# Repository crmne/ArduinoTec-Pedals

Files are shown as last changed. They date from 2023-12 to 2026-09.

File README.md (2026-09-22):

# ArduinoTec-Pedals

Turn an ATmega32u4 board, two analog pedal sensors and an HX711 load-cell
amplifier into standalone USB racing pedals. Originally made for Fanatec
ClubSport V1/V2 pedals; other pedals can work with compatible sensors and wiring.
The pedals connect to your **computer by USB**, separately from your wheelbase.

**0.2.0 release candidate 1:** intended for hardware testing, not a stable
release. The firmware builds for all three boards below and passes simulated
regression tests. It has not yet been tested on physical pedals. Read the
[release notes](docs/releases/0.2.0-rc.1.md) and do the checks below before
using it in a race.

This version adds saved calibration, automatic sensor direction detection,
a guided setup tool, a 1,000 Hz report target, brake fault detection, and builds
with pinned dependencies. Hardware limits still apply: the HX711 supplies
**10 or 80 new brake readings per second**, not 1,000.

## What you need

| Part | Requirement |
| --- | --- |
| Controller | Arduino Leonardo, Arduino Micro, or ATmega32u4 Pro Micro **5 V / 16 MHz** |
| Throttle and clutch | Analog sensors: stock compatible Hall sensors or potentiometers |
| Brake | Load cell connected to an HX711 amplifier, channel A |
| Wiring | USB data cable, connectors, insulated wire, mounting/strain relief |
| Tools | Multimeter; soldering iron, solder and heat shrink for permanent assembly |
| Computer | Arduino IDE for installation; Python 3.9+ for the guided setup tool |

Uno/Nano with ATmega328P, Teensy, RP2040, and 3.3 V / 8 MHz Pro Micro boards are
not targets of the supplied binaries. A board with a similar shape is not
necessarily compatible. Two-pedal builds are possible from source by setting
`CLUTCH_ENABLED` to `false`; downloadable defaults expect all three pedals.

The original Hall sensors' voltage rating must be established before powering
them. A 5 V controller does **not** mean an unknown sensor tolerates 5 V.
See [wiring and assembly](docs/wiring.md) for the pin table, load-cell types,
checks before connecting USB, and the original circuit drawing.

## 1. Wire and check the pedals

Follow [the wiring guide](docs/wiring.md). Prototype and verify sensor readings
before making permanent joints. Disconnect the original controller from any
sensors you reconnect here. Do not connect this USB controller to the wheelbase
pedal socket.

Default signals are throttle **A0**, clutch **A2**, HX711 **DT → D3** and
**SCK → D5**, with a common ground. Use the labels printed on your specific
board and module. The old brake sensitivity potentiometer is optional and
ignored by default: calibration now sets the pressure that means full braking.

## 2. Install the firmware

### Arduino IDE: the easiest starting point

1. Download this repository using **Code → Download ZIP**, then extract it.
2. Install [Arduino IDE](https://www.arduino.cc/en/software). In Boards Manager,
   install **Arduino AVR Boards 1.8.8**. For a Pro Micro, also install
   **SparkFun AVR Boards 1.1.13** using the additional board URL below.
3. In Library Manager, install **HX711_ADC 1.2.12** by Olav Kallhovd.
4. Download [ArduinoJoystickLibrary v2.1.1](https://github.com/MHeironimus/ArduinoJoystickLibrary/archive/refs/tags/v2.1.1.zip).
   In the IDE choose **Sketch → Include Library → Add .ZIP Library**.
5. Open `ArduinoTec-Pedals/ArduinoTec-Pedals.ino`. Keep **all files in that
   folder together**; downloading just the `.ino` does not work.
6. Select your board and USB port. For SparkFun Pro Micro, select
   **ATmega32U4 (5V, 16 MHz)** under Processor. Click **Upload**.
7. Close the IDE's Serial Monitor before using the setup tool.

SparkFun's additional Boards Manager URL (IDE Settings/Preferences):

```text
https://raw.githubusercontent.com/sparkfun/Arduino_Boards/master/IDE_Board_Manager/package_sparkfun_index.json
```

No pedal motion is reported until you complete and save calibration.

### Prebuilt firmware: no compilation

When available, download the `pedals-VERSION.zip` asset from
[Releases](https://github.com/crmne/ArduinoTec-Pedals/releases), or a development
artifact from [Actions](https://github.com/crmne/ArduinoTec-Pedals/actions).
Extract it. The package includes three board-specific HEX files, this guide,
and the setup tool. [The prebuilt installation guide](docs/install-prebuilt.md)
shows how to choose and upload the correct file without replacing your bootloader.

## 3. Calibrate once

Open a terminal in the extracted project/package folder. Create a Python
environment and install the small serial dependency:

```sh
python3 -m venv .venv
source .venv/bin/activate
python -m pip install -r tools/requirements.txt
python tools/pedals.py ports
```

On Windows, use `py -3 -m venv .venv`, then `.venv\Scripts\activate.bat` in
Command Prompt (or `.venv\Scripts\Activate.ps1` in PowerShell). The remaining
`python` commands are the same. On macOS, the port is typically
`/dev/cu.usbmodem…`; on Linux it is usually `/dev/ttyACM…`; Windows uses `COM…`.
Choose the port that appears when you plug in the pedals.

Replace the example port with yours:

```sh
python tools/pedals.py calibrate --port /dev/ttyACM0
```

The tool guides you through:

1. Release every pedal and keep your feet clear.
2. Hold throttle fully pressed, then clutch fully pressed.
3. Hold the brake at the pressure you want to represent **100% braking**.
4. Keep still during each capture (about 0.8 seconds).
5. Review the captured endpoints, release everything, and type **SAVE**.

Calibration is stored in the controller's EEPROM and survives power cycles.
It supports sensors whose readings increase or decrease when pressed. Default
deadzones are 0.5% at each end; `--deadzone-percent 1` sets 1% instead.
The brake capture sets a personal force preference; it is not a measurement
of kilograms without separate mechanical/load-cell calibration.

Press Ctrl+C or decline SAVE to cancel. Previous saved settings are retained.
An abandoned session expires after two minutes without a command. Keep games
closed during setup: output resumes after save, cancel or expiry. A subsequent
capture of the released position requires recapturing all full endpoints.

## 4. Check, then drive

```sh
python tools/pedals.py info --port /dev/ttyACM0
python tools/pedals.py monitor --port /dev/ttyACM0 --seconds 10
```

Check that every released pedal reports zero, each pressed pedal reaches 32767
in this tool, and the others remain at zero. Unplug/replug USB and verify the
calibration remains. The USB library maps this range into 16-bit HID fields;
your game or OS may display a different number for the same full travel.

In your game, bind throttle, brake and clutch separately. This firmware uses
the throttle, brake and Rx (clutch) axes. Clear old game calibration and rebind
if upgrading from the original firmware. The new USB device type is joystick;
Windows/Linux enumeration and individual games still need physical validation.

Linux tools such as `evtest` or `evdev-joystick` can inspect the event device.
`jscal` calibrates the separate legacy `/dev/input/js*` interface. They cannot
save settings on this controller; use the supplied tool for that. See
[calibration protocol and Linux notes](docs/calibration.md).

For a small brake-zero drift after warming up, release it and run:

```sh
python tools/pedals.py tare --port /dev/ttyACM0
```

This adjusts only the current session's brake zero while retaining its travel.
For a lasting change, run the full calibration again. The firmware never
silently tares a pressed brake when plugged in.

## Performance: what the numbers mean

| Part of the system | Capability / limit |
| --- | --- |
| Firmware report schedule | Target 1,000 reports/s, one complete report per interval |
| USB endpoint | Requests 1 ms polling; delivery depends on the host |
| Hall sensors | 10-bit ADC: up to 1,024 raw counts across the entire input voltage range |
| Brake ADC | HX711: 24-bit raw output, **10 or 80 samples/s** selected in hardware |
| Calibrated output | 0–32767 (32,768 possible values), mapped into 16-bit USB fields |
| Actual precision / end-to-end latency | Not measured yet; depends on mechanics, signal span, noise, filtering and host |

`monitor` reports observed firmware submission/sampling rates. Repeating the
latest brake reading at 1,000 Hz does not create new brake measurements.
80 Hz gives a new conversion about every 12.5 ms; 10 Hz gives one about every
100 ms. The HX711 and library filters add delay. The default library's filter
still uses three conversions even with `setSamplesInUse(1)`.

See [performance and measurement](docs/performance.md) for 80 Hz setup, the
filter tradeoff, and a validation checklist. We keep your existing hardware;
software cannot remove the HX711's conversion-rate limit.

## Troubleshooting

| Symptom | What to check |
| --- | --- |
| No serial port | Use a USB **data** cable, check the board selection and OS port permissions. Unplug/replug to identify it. |
| Port busy / access denied | Close Serial Monitor and other tools. On Linux inspect the device's group and follow your distribution's serial-access instructions; do not run the whole setup as root. |
| `BRAKE_NOT_READY` | Wait two seconds after power-on. Check HX711 power, ground, DT/D3 and SCK/D5; a stalled or saturated input is rejected. |
| `UNSTABLE_HOLD_STILL` | Repeat the capture holding the pedal still. Inspect loose wiring, sensor mounting and raw noise. The tool cancels the session on an error. |
| `TRAVEL_TOO_SMALL` | Check sensor/magnet movement or load-cell wiring; released and full readings are too close. |
| Pedals remain at zero | Run `info`; calibration may be missing or invalid. Check that the firmware configuration matches the saved calibration. |
| Brake falls to zero during use | No valid conversion arrived for 250 ms, or the input is invalid/saturated. Inspect the raw readings and wiring. |
| Upload fails | Select the exact board/clock. Pro Micro bootloaders may need reset/double-reset to expose a temporary upload port; see the board maker's instructions. |
| Missing header / wrong Joystick library | Keep the entire sketch folder and install the named library/version above; several unrelated libraries have similar names. |

## Development and releases

[Developer instructions](docs/development.md) cover tests, the pinned build
script, package contents and releases. Pushes and pull requests run simulated
firmware tests, setup-tool tests and builds for Leonardo, Micro and Pro Micro.
Version tags must match the firmware version and be reachable from `master`;
CI prepares a **draft release** with binaries, sources and checksums for review.

This project builds on [jssting/ArduinoTec-Pedals](https://github.com/jssting/ArduinoTec-Pedals).
The September 2026 firmware/setup changes are maintained here. The original
history, circuit assets and [GPL-3.0 license](LICENSE) are retained.

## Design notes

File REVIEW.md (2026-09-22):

# Initial review and improvement plan — 2026-09-22

This is the historical review before the calibration implementation. Its
remaining-work list and proposed protocol are superseded by the current
[README](README.md), [protocol](docs/calibration.md), and
[development/validation guide](docs/development.md). Hardware validation remains
outstanding.

User-visible UI impact: no graphical UI changes. The reliability patch changes
pedal reports on zero/negative readings and near deadzones. Physical pedal and
game testing is still required before claiming a hardware issue resolved.

The project is a useful, small hardware prototype. Its main weakness is implicit
calibration and fragile sampling/output behavior, not a need for more classes.
Keep the sketch as orchestration; extract only shared arithmetic and persistent
configuration that can be tested without hardware.

## Reliability patch

- Always report each axis, including a sensor reading of zero. Previously the
  `val > 0` guards left old values on USB; a released brake could stay pressed,
  and a decreasing Hall sensor reaching ADC zero could stop updating.
- Retain the last brake conversion between HX711 samples. Previously a local
  variable reset to zero every loop and output depended on the guards above.
- Poll HX711 from the main loop. Previously `getData()` could read the multi-byte
  sample dataset while the interrupt modified it. The library supports polling.
- Clamp negative brake readings to zero and bound positive float-to-int
  conversion before applying the sensitivity pot and output limits.
- Share deadzone clipping across axes, apply the brake lower deadzone after
  sensitivity adjustment, and prevent a negative ceiling during startup.
- Use the same dual-input averaging for baseline capture and live readings.
- Send one complete USB report per loop instead of a report per setter.

## Remaining work, in priority order

1. **Explicit, persistent calibration.** Startup baselines require released
   pedals, use a maximum of 25 samples, and cannot distinguish noise from rest.
   Continuously learned maxima move when an outlier arrives and only clip;
   they do not map physical full travel to USB full scale. Store released and
   fully pressed endpoints, direction, deadzones, and desired brake force.
   Normalize each calibrated axis to 0–1023 with 32-bit intermediate math;
   reject endpoints with insufficient span. Avoid `abs()` treating movement
   in the wrong direction as valid pressure.
2. **Sensor health and noise.** A disconnected HX711 can retain its last brake
   value indefinitely, and startup failure loops forever. Add a timestamp and
   explicit fault status, decide a timeout from measured 10/80 SPS behavior,
   and report a neutral brake after timeout. Handle a faulted Hall input where
   detectable. Measure idle noise first, then choose a small filter with a
   measured latency budget. `setSamplesInUse(1)` requests minimal averaging;
   do not claim increasing it cures wiring or power faults.
3. **Predictable timing.** Remove debug `delay(100)` calls and dynamic `String`
   construction; rate-limit diagnostics without blocking. Establish a USB
   reporting cadence independently of sensor conversion timing. Measure timing
   on hardware with debug on/off, including USB host disconnection.
4. **Compatibility and repeatable builds.** Check Windows enumeration before
   changing `JOYSTICK_TYPE_MULTI_AXIS`; upstream #6 reports improvement with
   `JOYSTICK_TYPE_JOYSTICK`. Preserve existing axis usage mappings unless game
   tests justify changing them. Add CI builds with pinned AVR core/libraries
   and host regression tests. Remove or implement the unused `use_Dual_Brk`
   option. Confirm each board's physical pins against the schematic.

## Calibration design proposal (not implemented)

Keep standard USB HID for driving: games should need no custom driver. Reuse
USB serial, already present, for setup. Start with a tiny line-based protocol,
not a custom HID driver or web application:

| Proposed command | Purpose |
| --- | --- |
| `INFO` | Protocol version, firmware version, calibration/fault status |
| `READ` | Raw and normalized readings, age of last brake sample |
| `CAL BEGIN` | Start a separate candidate calibration |
| `CAL REST` | Capture stable released positions and tare brake asynchronously |
| `CAL FULL throttle`, `CAL FULL clutch`, `CAL FULL brake` | Capture full travel or desired maximum braking force |
| `CAL SHOW` | Review candidate endpoints, direction and deadzones |
| `CAL SAVE` | Validate, write EEPROM once, activate calibration |
| `CAL CANCEL` | Discard candidate and retain active calibration |

Use bounded input buffers, explicit `OK`/`ERR` replies, and completion replies
for asynchronous operations. Keep the existing `t` command compatible. Never
write EEPROM on every loop. Use versioned records with integrity checking,
defaults for invalid data, and two slots so a power interruption during save
leaves the previous record available. Define safe behavior while calibrating
and reject save until all required captures are valid.

A small serial CLI can guide the user through this process on Linux, Windows
and macOS. Existing Linux evdev tools remain useful for verifying output and
host adjustment; they cannot send this proposed protocol without an extension.
Only build a custom GUI once the calibration workflow is proven on hardware.

## Upstream issues

Reviewed the four open issues in `jssting/ArduinoTec-Pedals`:

| Issue | Assessment and next action |
| --- | --- |
| [#17: sensor voltage](https://github.com/jssting/ArduinoTec-Pedals/issues/17) | Requires identification and ratings of the actual Hall sensor. A firmware change cannot establish that 5 V is safe for a sensor powered at 3.3 V by its stock board. Leave open. |
| [#16: wheelbase connection](https://github.com/jssting/ArduinoTec-Pedals/issues/16) | This sketch is a USB peripheral. Direct wheelbase support needs protocol/electrical investigation and likely another interface. Leave open. |
| [#15: input noise](https://github.com/jssting/ArduinoTec-Pedals/issues/15) | Need per-axis raw recordings, sensor details and sampling/filter measurements. The sampling fixes here are not proof that the reporter's Hall noise is resolved. Leave open. |
| [#13: upload/build help](https://github.com/jssting/ArduinoTec-Pedals/issues/13) | Existing reply suspects a missing `confOptions.h`. README now explicitly requires the complete sketch folder. Reporter confirmation is needed to call it resolved. |

Closed issues also expose useful documentation gaps: #12 documents Teensy
incompatibility with this joystick implementation (README corrected), and #6
reports Windows joystick recognition problems (needs device testing).

No upstream closure or resolution claim is warranted from software tests alone.

## Validation

- Host regression executable passed with GCC, `-Wall -Wextra -Werror`, address
  sanitizer and undefined-behavior sanitizer.
- Arduino CLI 1.5.1 builds passed for `arduino:avr:leonardo` and
  `arduino:avr:micro`, using Arduino AVR core 1.8.8, HX711_ADC 1.2.12 and
  ArduinoJoystickLibrary v2.1.1. Usage: approximately 16 KB flash and 801 bytes
  global RAM. A Micro build is not a physical Pro Micro validation.
- Pre-commit formatting and general file checks passed. Its cppcheck and
  cpplint hooks could not run because those executables are absent locally.
- No firmware was flashed; electrical operation, pedal feel, USB enumeration,
  Linux calibration tools and behavior in games have not been tested.

To reproduce the board builds after installing the versions above:

```sh
arduino-cli compile --fqbn arduino:avr:leonardo ArduinoTec-Pedals
arduino-cli compile --fqbn arduino:avr:micro ArduinoTec-Pedals
```

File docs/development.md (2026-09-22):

# Development and release process

The sketch handles hardware, scheduling and the serial protocol.
`calibration.h` contains normalization/capture rules; `calibrationStore.h`
contains a small two-slot EEPROM store with explicit byte encoding. Keep these
independent of Arduino so the behavior can be exercised on a host compiler.
`tools/pedals.py` is a thin serial client; it does not duplicate calibration math.

## Run tests

From the repository root:

```sh
g++ -std=c++11 -Wall -Wextra -Werror -fsanitize=address,undefined \
  -Itests/stubs tests/pedals_test.cpp -o /tmp/pedals-test
/tmp/pedals-test
python3 -m unittest discover -s tests -p 'test_*.py'
```

Firmware tests compile the actual sketch against simulated Arduino, HX711,
EEPROM and joystick interfaces. They cover monotonic/reversed calibration,
bounds, captures, serial framing, cancellation, stale/invalid brake readings,
rate scheduling, temporary tare, corrupt EEPROM, hardware-profile mismatch,
and simulated power loss at every byte mutation in a save. The setup tests
cover protocol responses, save/cancel, errors and interruption, and run the
actual Python wizard against a compiled firmware simulator.
These tests do not validate USB/electrical behavior or benchmark an AVR CPU.

## Build and package

Install **Arduino CLI 1.5.1**, Git and Python 3.9+. Then:

```sh
python3 tools/build.py --setup
```

This downloads pinned Arduino AVR 1.8.8, SparkFun AVR 1.1.13, HX711_ADC 1.2.12
and ArduinoJoystickLibrary v2.1.1 (verified against its commit). Dependencies
live under ignored `build/toolchain`, separate from your regular Arduino IDE.
The script uses the public Arduino/SparkFun package indexes and GitHub; initial
setup requires network access. Later builds can omit `--setup`.

The build checks installed core/library versions, compiles all three board
profiles, and writes **`build/dist/`**. It replaces that generated directory on
each run. Dependency versions and source commit are recorded in the manifest.
Pinning versions is for repeatable inputs; bit-for-bit reproducibility across
all operating systems has not been established.

The package contains:

- Application-only HEX images for Leonardo, Micro and 5 V / 16 MHz Pro Micro.
- A ZIP with those images, manifest, README, circuit drawing, guides and tools.
- A source archive with our firmware/tools/tests and the exact library/core
  source trees used by the build, including their license notices.
- SHA256SUMS for every generated asset.

The source archive can be extracted and built using `tools/build.py --setup`.
It has no Git metadata; the supplied manifest identifies its source revision.
The `vendor` directory preserves dependency sources for inspection and manual
Arduino setups. AVR compiler/tool packages are obtained through the pinned
board package indexes rather than embedded in the source archive.

## Configuration and compatibility

Edit `confOptions.h` only when building from source. `CLUTCH_ENABLED=false`
allows two pedals; `BRAKE_POT_ENABLED=true` restores post-calibration sensitivity
scaling from A3. Dual-input options average paired compatible sensor outputs.
These options contribute to the EEPROM profile key. Increment
`CALIBRATION_PROFILE` when changing pin assignments or raw sensor processing
so old endpoints cannot be silently reused. Do not simply increase the report
rate constant expecting the HX711 to sample faster.

The joystick USB type is now `JOYSTICK_TYPE_JOYSTICK`. Axis usages remain Rx,
throttle and brake. Host/game re-enumeration and re-binding may be necessary.
Changing hardware options requires firmware upload and recalibration; the
release binaries intentionally use one documented default configuration.

## Release CI

Pushes to `master`, pull requests and manual runs execute tests and build all
three boards. The resulting `pedals-firmware` Actions artifact is suitable for
preview testing, with its validation limitations clearly stated. On version
tags, the same workflow additionally verifies:

1. The tag format is `vX.Y.Z`, `vX.Y.Z-rc.N` or `vX.Y.Z-beta.N`.
2. `PEDALS_VERSION` in `version.h` exactly matches the tag without `v`.
3. The tagged commit is an ancestor of the repository's default branch.
4. The checkout is the tagged commit and has no local modifications.

Only after successful tests/builds does the release job use write permissions
to create a **draft GitHub release** with all assets. Ordinary pushes and pull
requests have no release-write permissions.

For a release, commit the version and release notes to `master`, push it, and
run the hardware checklist. Create/push a version tag only at that reviewed
commit. CI prepares the draft; inspect its assets and hardware-validation notes
before publishing. Mark a first hardware-test candidate as a prerelease. A
passing build alone must not be presented as a tested stable hardware release.

## Hardware acceptance checklist

Record the board, sensor/cell, HX711 module/rate, wiring configuration, OS and
game versions along with results:

- [ ] Correct port and joystick enumeration on physical hardware.
- [ ] No output before calibration, during capture, or during warm-up.
- [ ] All axes reach zero/full; increasing and decreasing sensor directions work.
- [ ] Settings survive a power cycle; cancellation preserves the saved record.
- [ ] Unplugged/stalled HX711 releases brake after timeout and recovers sensibly.
- [ ] Idle/fixed-pressure noise is acceptable and no axis sticks after release.
- [ ] Observed USB and sensor rates are recorded; no unsupported latency claims.
- [ ] Serial monitor disconnect and USB suspend/resume behave acceptably.
- [ ] Target games bind all axes and apply expected brake pressure.

## Project identity

Keeping the GitHub fork relationship does not prevent independent releases or
maintenance. Preserve original attribution, history and license. GitHub's
[detach documentation](https://docs.github.com/en/pull-requests/how-tos/work-with-forks/detaching-a-fork)
states that detachment is permanent and lists metadata that is not retained.
Decide on detachment after a hardware-tested release, with an inventory/backup
of repository metadata. No detachment or repository deletion is performed by
these scripts.

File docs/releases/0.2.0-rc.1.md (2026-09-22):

# ArduinoTec-Pedals 0.2.0-rc.1

First release candidate for the new calibration firmware and setup experience.

**For hardware testing: physical pedal operation, USB enumeration, game compatibility and end-to-end latency have not yet been validated.**

## Download and install

Download **pedals-0.2.0-rc.1.zip** for the firmware, setup tool and guides. Choose the HEX matching your board: Leonardo, Micro, or Pro Micro **5 V / 16 MHz**.

Follow the included README and prebuilt installation guide. The source archive includes the firmware, tests, tools, libraries and board-core sources. SHA256SUMS covers the downloadable assets.

## Changes

- Guided calibration for released positions, full travel and desired maximum brake pressure, with automatic sensor direction detection and deadzones.
- Calibration saved in two EEPROM slots with integrity checks and recovery from interrupted saves; temporary brake tare does not write EEPROM.
- Correct pedal release reporting, retained brake samples between conversions, and neutral brake output for stale or invalid readings.
- One complete USB report per interval, targeting 1,000 reports/second, with serial diagnostics for observed firmware sampling/submission rates.
- Pinned builds for three boards, automated regression tests, downloadable packages and installation, wiring, calibration and performance guides.

## Upgrading and limitations

**Run calibration after installing this firmware for the first time.** Outputs remain neutral until valid calibration is saved. Close games during setup; outputs resume after save, cancel or session expiry. Existing game bindings may need to be cleared and rebound because the USB device type is now joystick. Axis usages remain throttle, brake and Rx for clutch.

Default images expect three pedals. The old sensitivity potentiometer is disabled by default; saved brake calibration sets maximum pressure. Two-pedal builds, custom wiring and optional potentiometer support require a source build.

The HX711 still supplies only 10 or 80 fresh brake conversions per second, selected in hardware. The 1,000 Hz report target is not a measured sensor rate or latency guarantee. Hall inputs retain the ATmega32u4's 10-bit ADC limits.

Software validation covers simulated firmware behavior, EEPROM interruption, the setup tool talking to a compiled firmware simulator, and builds for all three board profiles.

Before driving, verify released/full travel, persistence across power cycles, brake fault recovery, noise and game bindings on your actual hardware. Include board, sensor, HX711 rate, OS and firmware version in any test report.

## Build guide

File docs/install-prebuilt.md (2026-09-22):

# Install a prebuilt firmware image

A firmware HEX is the program for the controller; uploading it does not require
compiling C++. Keep the existing bootloader. These instructions use
[Arduino CLI](https://arduino.github.io/arduino-cli/1.5/installation/), available
for Linux, macOS and Windows. If you prefer buttons to terminal commands, use
the Arduino IDE instructions in [README](../README.md).

## Pick the board image

| Your board | File | Board identifier (FQBN) |
| --- | --- | --- |
| Arduino Leonardo | `pedals-leonardo.hex` | `arduino:avr:leonardo` |
| Arduino Micro | `pedals-micro.hex` | `arduino:avr:micro` |
| SparkFun-compatible Pro Micro, 5 V / 16 MHz | `pedals-promicro-5v16.hex` | `SparkFun:avr:promicro:cpu=16MHzatmega32U4` |

Do not choose Micro just because a Pro Micro is small. Board variant, USB IDs,
clock and bootloader configuration matter. The default images have a throttle,
clutch and brake; custom pins, two pedals or the optional pot require a source
build. A board's EEPROM calibration persists through normal firmware upload,
but an incompatible calibration schema/profile will require setup again.

## Upload

Extract the release ZIP. Install Arduino CLI 1.5.1 and the matching board core:

```sh
arduino-cli core update-index
arduino-cli core install arduino:avr@1.8.8
```

For a Pro Micro, also run:

```sh
arduino-cli core update-index --additional-urls https://raw.githubusercontent.com/sparkfun/Arduino_Boards/master/IDE_Board_Manager/package_sparkfun_index.json
arduino-cli core install SparkFun:avr@1.1.13 --additional-urls https://raw.githubusercontent.com/sparkfun/Arduino_Boards/master/IDE_Board_Manager/package_sparkfun_index.json
```

List connected boards:

```sh
arduino-cli board list
```

Close the game, Serial Monitor and setup tool. Replace the port and board/file
below with your selections. For a **Leonardo** on Linux:

```sh
arduino-cli upload --fqbn arduino:avr:leonardo --port /dev/ttyACM0 --input-file pedals-leonardo.hex --verify
```

For a **5 V / 16 MHz Pro Micro**, the board argument is
`--fqbn SparkFun:avr:promicro:cpu=16MHzatmega32U4` and the file is
`pedals-promicro-5v16.hex`. On Windows use the `COM` port from `board list`;
on macOS use its `/dev/cu.*` port. During reset the bootloader may enumerate
on a different port. Use the reset procedure documented for your board if
automatic reset fails, then upload while that port is present.

These are application-only images. Do not use “Burn Bootloader,” change fuses,
or erase EEPROM to install them. After uploading, return to
[step 3: calibration](../README.md#3-calibrate-once).

## Verify downloads

The release also supplies `SHA256SUMS`, covering the ZIP, source archive,
individual HEX files and manifest. Download the assets you wish to verify.
Compare a file's `sha256sum FILE` output (Linux), `shasum -a 256 FILE` (macOS),
or `Get-FileHash FILE -Algorithm SHA256` (PowerShell) against its entry.
The manifest records the source commit, board identifiers and dependency
versions; it does not certify physical hardware testing.

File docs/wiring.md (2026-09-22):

# Wiring and assembly

Start with the board disconnected from USB and the pedals disconnected from
all other controllers. These instructions cover the default three-pedal build.
They are a wiring guide, not confirmation that every Fanatec revision uses the
same sensors, colors or supply voltage.

## Pin table

| Signal | Controller / connection |
| --- | --- |
| Throttle analog output | A0 |
| Clutch analog output | A2 |
| HX711 DT / DOUT | Digital pin 3 |
| HX711 SCK / CLK | Digital pin 5 |
| HX711 ground | Controller GND |
| HX711 supply | Per module specification; the intended controller is 5 V |
| Hall sensor grounds | Controller GND |
| Hall sensor supplies | Their rated supply, verified before connecting |
| Optional sensitivity pot wiper | A3; ignored unless `BRAKE_POT_ENABLED` is enabled |
| Optional second throttle / clutch output | A5 / A8; source configuration required |

Use analog pin names, not the board's physical pin position. An A5 or A8
connection is unnecessary for the default single-output sensors. Dual-input
mode averages two compatible outputs; it does not double ADC resolution.
Only enable it for sensors whose two outputs should be averaged.

All connected modules need a common signal ground. Sensor output voltage must
stay within the controller ADC's input range. Original sensors supplied with
3.3 V by their stock board must not be assumed safe at 5 V. Identify the part
or establish its rating before choosing the supply. Never power the same
sensor from both the original controller and this board.

## Load-cell connection

For a **four-wire full bridge**, use the cell manufacturer's pinout:
excitation +/− to HX711 E+/E−, signal +/− to A+/A−. Wire colors vary. This
firmware uses channel A at gain 128. Reversed signal polarity is handled by
calibration, provided the electrical input remains within the ADC's range.

A **three-wire half bridge** needs bridge completion or a compatible second
half bridge. The original example uses two 1 kΩ resistors to complete the
bridge. Do not assume those resistors or that diagram apply to a four-wire
cell, and do not identify excitation/signal solely by color. Confirm the cell
wiring and resistance arrangement with its documentation and a meter first.

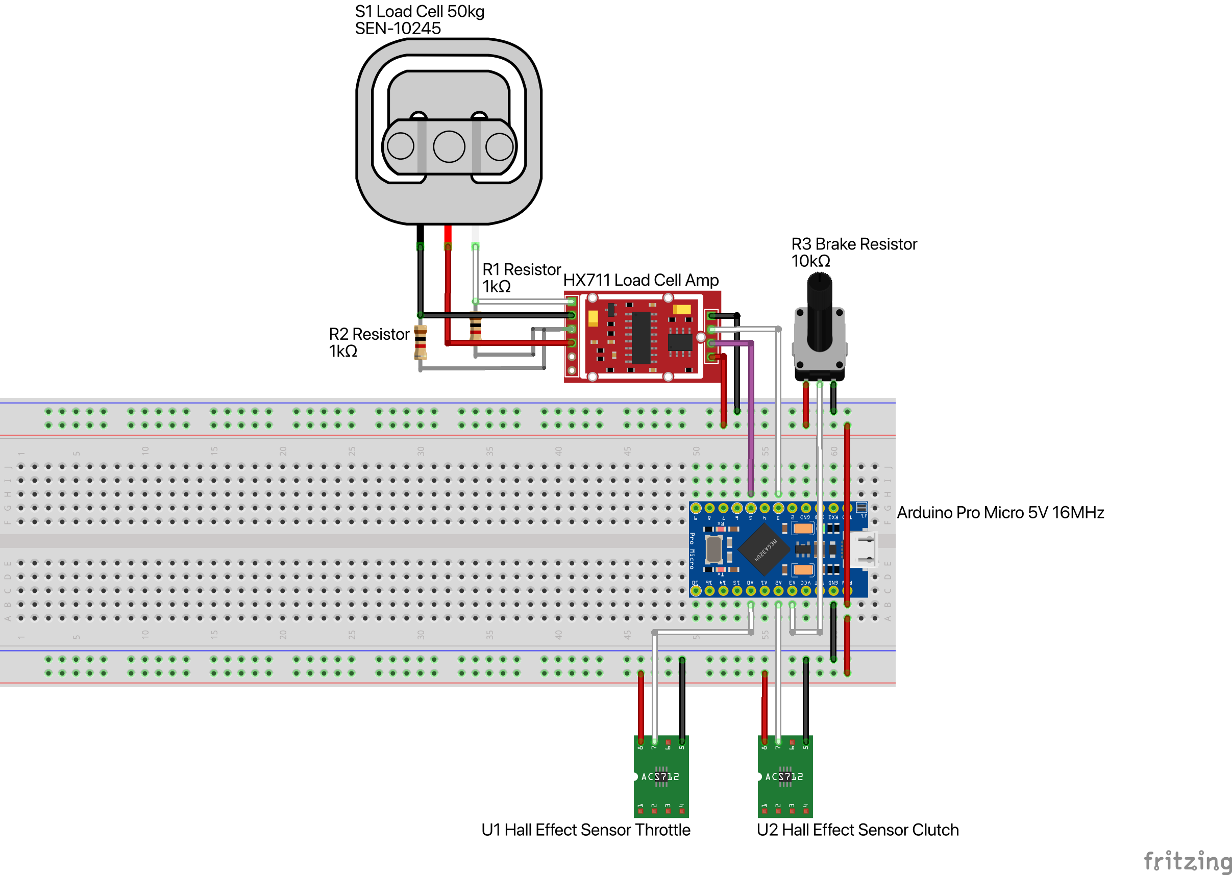
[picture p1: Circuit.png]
Original project wiring example


The drawing is the historical Pro Micro/three-wire-load-cell example. It shows
particular sensor modules and an optional brake pot; it is not a verified
pinout for every ClubSport V1/V2 sensor or HX711 breakout. The table above and
the labels/datasheets of your actual parts take precedence. The editable
original is [Circuit.fzz](../Circuit.fzz) (in the repository/source archive).

## Prototype before soldering

1. Identify board, sensor and cell pins. Label wires before removing the old
   controller. Photograph your own wiring for future reference.
2. Mount Hall sensors so the magnet moves smoothly through a useful part of
   their range. The output should change gradually, not switch on/off. Adjust
   position without allowing bare contacts to touch the metal pedal frame.
3. Connect signal grounds, then the intended supplies and signals. Keep bridge
   signal wires short and away from noisy power wiring; secure all connectors.
4. With power off, inspect polarity, shorts and continuity. Do not rely on a
   breadboard rail continuing through a center split.
5. Power from USB, install the firmware, and use `monitor` to verify that moving
   each pedal changes its own raw value. Ensure nothing heats unexpectedly.
6. Calibrate and confirm stable endpoints before making permanent joints.

## Permanent assembly

Cut and strip only enough insulation for the joint. Tin the wire and pad, make
a clean joint, and insulate exposed connections with heat shrink. Avoid long
bare sections and solder bridges. Add strain relief so pedal movement and USB
cable pulls cannot load a solder joint. Mount the controller/amplifier on
insulating standoffs inside a suitable enclosure, away from the moving pedal
mechanism. Inspect continuity again with USB unplugged, then repeat calibration
and the release/full-travel checks.

## HX711 at 80 samples/second

The HX711 **RATE** pin selects 10 SPS when low and 80 SPS when high. Modules
expose this as a switch, solder jumper, pad, or not at all. The meaning of an
open/closed jumper differs between designs: inspect the module schematic and
follow its manufacturer's instructions. Power off before changing a jumper.
Do not bridge unknown pads or connect a pin that is already grounded to supply.

The firmware cannot select RATE through DT/SCK. After a supported change,
recalibrate and observe `Valid brake conversions` in the monitor; it should
be near 80 rather than 10 Hz under a responsive host. See the
[HX711 datasheet](https://image.dfrobot.com/image/data/SEN0160/hx711_english.pdf)
and [performance notes](performance.md).

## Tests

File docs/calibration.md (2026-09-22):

# Calibration protocol and Linux integration

The normal gaming interface is USB HID. Configuration uses the board's USB
serial port at **57600 baud**, with ASCII commands terminated by newline.
Only one application should open the serial port at a time. There is no custom
Linux kernel driver or privileged service to install.

Protocol version **1** returns one `OK ...` or `ERR ...` line per command.
A capture returns `OK WAIT`, followed by `OK CAPTURE` or an error after about
800 ms. Wait for completion before sending another command. `INFO` identifies
the protocol; clients should reject unknown versions. Maximum command length
is 63 characters, excluding newline; overflow discards the entire line.
The retained single-byte lowercase `t` command also works without newline.

| Command | Meaning |
| --- | --- |
| `INFO` | Firmware/protocol version, saved-calibration flag, session, clutch, brake health and report target |
| `READ` | Absolute raw and normalized throttle/clutch/brake values; brake health/age; uptime and cumulative report/sample counters |
| `CAL BEGIN` | Begin a candidate calibration; outputs become neutral |
| `CAL REST` | Hold all pedals released; capture stable absolute rest readings |
| `CAL FULL throttle` | Hold throttle fully pressed and capture its endpoint |
| `CAL FULL clutch` | Hold clutch fully pressed and capture its endpoint (if enabled) |
| `CAL FULL brake` | Hold desired maximum braking force and capture it |
| `CAL DZ throttle 5 5` | Set lower/upper deadzones in parts per thousand (0–100 each); replace axis as appropriate |
| `CAL SHOW` | Show candidate calibration in a session, otherwise active calibration |
| `CAL SAVE` | Validate all required captures, save and activate |
| `CAL CANCEL` | Discard candidate, resume active settings; also cancels a temporary tare capture |
| `TARE` or `t` | Capture a new released brake zero, preserving span, until reboot; requires existing calibration |

Readings are ordered **throttle, clutch, brake**. Hall raw values are 0–1023.
Brake raw values are the HX711 library's unsigned-offset representation of the
ADC output (0–16777215), with no scale factor or automatic boot tare. They are
not kilograms. Values at the brake ADC rails are invalid. `out` is 0–32767;
zero may also mean calibration mode, warm-up or a brake fault, so inspect status.

Calibration rejects Hall spans below 32 counts and brake spans below 4096 raw
counts. Captures require at least 100 Hall samples and four brake samples;
peak-to-peak variation must be at most eight Hall counts or 1000 brake counts.
These are initial validation limits, not claims about measured sensor quality.
A reversed span is valid. Recapturing REST invalidates prior full captures.

Two EEPROM slots use a schema version, hardware-profile key, generation counter
and CRC. A save commits its target slot last and leaves the previous slot
untouched. No writes occur during normal driving or temporary tare. Calibration
is invalidated when compiled sensor options/profile change. First boot and
invalid records produce neutral output until calibration. All axes are neutral
through the initial two-second sensor warm-up and while calibrating.
A stale (250 ms) or invalid brake reading neutralizes only the brake.
An abandoned calibration expires after 120 seconds without a command.

## Reusing Linux tools

[`evdev-joystick`](https://man.archlinux.org/man/extra/linuxconsole/evdev-joystick.1.en)
can inspect/change axis limits and flat/fuzz settings for `/dev/input/event*`.
Use `--listdevs` and `--showcal DEVICE` to identify the actual pedals. `evtest`
is useful for observing events. A GUI candidate is
[Calibrate Joystick](https://github.com/dkosmari/calibrate-joystick), which saves
host profiles; it has not been tested with this hardware.

[`jscal` and `jstest`](https://kernel.org/doc/html/latest/input/joydev/joystick-api.html)
work on the separate legacy `/dev/input/js*` interface. A correction there
should not be assumed to affect a game using evdev. Games may have their own
calibration too.

These tools can verify or adjust what Linux receives. They do not implement
this serial protocol or write the pedal EEPROM. The supplied CLI is the small
piece needed for that, and a future GUI can reuse exactly the same commands.

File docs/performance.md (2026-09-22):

# Performance and measurement

## Three different rates

1. **USB polling:** the pinned Joystick library requests a 1 ms interrupt
   endpoint interval. That is a host polling opportunity, not proof that the
   firmware or a game processes a fresh sensor value each millisecond.
2. **Firmware sampling/reporting:** this firmware targets a 1 ms interval for
   Hall reads and one complete HID report. It skips missed intervals instead
   of replaying a backlog. Serial work is bounded and there are no debug sleeps
   or heap-allocated strings in the main loop. A stalled USB host can still
   delay the Arduino USB stack; it is not a hard real-time guarantee.
3. **Brake conversions:** the HX711's internal oscillator supports 10 or 80 SPS,
   chosen by its RATE pin. Those correspond to approximately 100 or 12.5 ms
   between fresh conversions. Faster reports reuse the latest conversion.

The earlier sketch had no explicit report schedule and sent a separate USB
report from each axis setter. Its exact rate was not measured. This version's
1,000 Hz target is a scheduling choice, not a measured speedup claim.

## Precision is not the size of a USB field

The ATmega32u4 Hall inputs have a 10-bit ADC. The theoretical maximum is 1024
levels over the full ADC voltage range; if the mechanism produces only 300
counts of travel, there are roughly 300 useful position intervals before
noise. Rescaling into more USB numbers does not create physical information.
Good magnet alignment, a useful voltage span, stable supply and solid mechanics
matter more than increasing the reported bit count.

The HX711 returns 24 bits, but those are not 24 noise-free bits of brake force.
The new firmware retains its raw readings for calibration instead of dividing
by a fixed scale factor and truncating into a small integer range. Normalization
produces 0–32767: up to 32768 distinguishable output values, subject to raw span
and noise. The Joystick library maps them into 16-bit HID fields. This input
range also avoids overflowing the library's signed 32-bit mapping intermediate.

Calibration uses a linear response with lower/upper deadzones and handles
increasing/decreasing sensors. There is no response curve, oversampling claim,
or effective-bit claim based only on the ADC specification.

## Filtering and latency

With HX711_ADC 1.2.12, `setSamplesInUse(1)` still includes its default high- and
low-outlier rejection. That makes the output a median of three conversions,
not an unfiltered sample. A monotonic transition normally gains about one
sample interval of software-filter delay. The ADC also filters internally;
the datasheet quotes 400 ms settling at 10 SPS and 50 ms at 80 SPS after a
reset/gain/channel change. Those settling figures are not interchangeable with
total measured pedal-to-game latency.

Changing to 80 SPS improves responsiveness but the datasheet specifies higher
input noise (90 nV RMS versus 50 nV RMS at gain 128). Keep the short filter until
bench measurements justify changing it. Use the module's documented RATE
configuration; there is no firmware command to overclock the HX711.

## Measure your actual pedals

Run `python tools/pedals.py monitor --port PORT --seconds 10` after calibration.
It reports changes in firmware counters divided by device uptime:

- USB reports **submitted** to the library per second.
- Hall sample pairs per second.
- Valid brake conversions per second (expect near 10 or 80).

Telemetry adds some work. It does not count USB packets received by the host,
measure noise bandwidth, or measure end-to-end latency. For stronger evidence:

1. Log idle and fixed-pressure raw readings and quantify peak-to-peak and RMS
   noise relative to the calibrated span. Capture individual conversions with
   dedicated instrumentation; the 10 Hz terminal monitor is insufficient for
   an 80 SPS noise spectrum.
2. Inspect USB endpoint descriptors (`lsusb -v`) and actual interrupt transfers
   with a USB capture/logic analyzer. Timestamp sensor transitions and host
   events using a shared reference before claiming end-to-end latency.
3. Test full release, fast repeated presses, different USB ports/hubs, serial
   monitoring, host suspend/resume, and a disconnected brake module.
4. Run the intended game, verify bindings/endpoints, and compare stability with
   monitoring turned off. Game rendering/physics/input scheduling adds latency.

An HX711 at 80 SPS can be substantially more responsive than the same hardware
at 10 SPS. For genuinely fresh brake measurements at hundreds or thousands of
Hz, a different ADC/interface would be needed. That is outside this hardware
version; the wheelbase does not alter these sensor limits.

## Sources

- [HX711 manufacturer datasheet](https://image.dfrobot.com/image/data/SEN0160/hx711_english.pdf): rates, resolution, filtering/settling and noise.
- [Arduino analogRead reference](https://docs.arduino.cc/language-reference/en/functions/analog-io/analogRead/): ADC resolution and AVR analog-reading behavior.
- [HX711_ADC 1.2.12 configuration](https://github.com/olkal/HX711_ADC/blob/1.2.12/src/config.h): sample and outlier-filter settings.
- [Joystick v2.1.1 USB endpoint](https://github.com/MHeironimus/ArduinoJoystickLibrary/blob/v2.1.1/src/DynamicHID/DynamicHID.cpp): 1 ms endpoint request.
- [Joystick v2.1.1 mapping](https://github.com/MHeironimus/ArduinoJoystickLibrary/blob/v2.1.1/src/Joystick.cpp): report size and integer mapping.

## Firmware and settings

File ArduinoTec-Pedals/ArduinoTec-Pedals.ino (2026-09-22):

// ArduinoTec-Pedals: persistent calibration and serial setup, September 2026.
// Derived from jssting/ArduinoTec-Pedals; distributed under GPL-3.0 (LICENSE).
#include <Arduino.h>
#include <EEPROM.h>
#include <HX711_ADC.h>
#include <Joystick.h>
#include <stdarg.h>
#include <stdio.h>
#include <string.h>

#include "calibrationStore.h"
#include "confOptions.h"
#include "version.h"  // NOLINT(build/include_subdir): Arduino sketch-local header.

using pedals::Calibration;
using pedals::kBrake;
using pedals::kClutch;
using pedals::kThrottle;

Joystick_ Joystick(JOYSTICK_DEFAULT_REPORT_ID, JOYSTICK_TYPE_JOYSTICK, 0, 0,
                   false, false, false, CLUTCH_ENABLED, false, false, false,
                   true, false, true, false);
HX711_ADC LoadCell(HX711_dout, HX711_sck);
const uint32_t hardwareProfile = CALIBRATION_PROFILE * 16 + CLUTCH_ENABLED +
                                 2 * use_Dual_Thr + 4 * use_Dual_Cl +
                                 8 * BRAKE_POT_ENABLED;
pedals::CalibrationStore<EEPROMClass> storage(EEPROM, hardwareProfile,
                                              CLUTCH_ENABLED);
Calibration active = {}, candidate = {};
bool calibrated = false, session = false, brakeFault = true;
int32_t sensorRaw[3] = {};
uint16_t output[3] = {};
uint32_t startedMs, lastBrakeMs, lastFrameUs, lastCommandMs;
uint32_t reports = 0, hallSamples = 0, brakeSamples = 0;
uint8_t capturesDone = 0;
// -1: idle; 0..2: full endpoint; 3: all rest endpoints; 4: temporary brake
// tare.
int8_t capturing = -1;
uint32_t captureStarted;
pedals::Capture captures[3];
char command[64] = {}, response[256] = {};
uint8_t commandLength = 0;
bool overflow = false;
uint16_t responseLength = 0, responsePosition = 0;

void reply(const char* format, ...) {
  va_list args;
  va_start(args, format);
  int count = vsnprintf_P(response, sizeof(response) - 1, format, args);
  va_end(args);
  if (count < 0 || count >= static_cast<int>(sizeof(response) - 1)) {
    count = sizeof("ERR RESPONSE_SIZE") - 1;
    memcpy(response, "ERR RESPONSE_SIZE", count);
  }
  response[count++] = '\n';
  responseLength = count;
  responsePosition = 0;
}

bool brakeHealthy(uint32_t now) {
  return uint32_t(now - startedMs) >= SENSOR_WARMUP_MS && brakeSamples >= 3 &&
         !brakeFault && uint32_t(now - lastBrakeMs) <= BRAKE_TIMEOUT_MS;
}

void neutral() {
  for (uint8_t i = 0; i < 3; ++i) output[i] = 0;
}

void sendReport() {
  Joystick.setThrottle(output[kThrottle]);
  Joystick.setRxAxis(output[kClutch]);
  Joystick.setBrake(output[kBrake]);
  Joystick.sendState();
  ++reports;  // Submitted reports, not a measurement of host USB delivery.
}

int readPedal(int pin, int secondPin, bool dual) {
  int value = analogRead(pin);
  return dual ? (value + analogRead(secondPin)) / 2 : value;
}

void setup() {
  Serial.begin(57600);
  pinMode(Throttle, INPUT);
  if (CLUTCH_ENABLED) pinMode(Clutch, INPUT);
  if (use_Dual_Thr) pinMode(Throttle_I2, INPUT);
  if (CLUTCH_ENABLED && use_Dual_Cl) pinMode(Clutch_I2, INPUT);
  if (BRAKE_POT_ENABLED) pinMode(BrakeResistance, INPUT);
  LoadCell.begin();
  LoadCell.setSamplesInUse(
      1);  // Default library also rejects one high/low sample.
  LoadCell.setCalFactor(1.0f);
  LoadCell.setTareOffset(
      0);  // Keep absolute readings; saved endpoints define zero.
  calibrated = storage.load(&active);
  Joystick.setRxAxisRange(0, pedals::kOutputMax);
  Joystick.setThrottleRange(0, pedals::kOutputMax);
  Joystick.setBrakeRange(0, pedals::kOutputMax);
  Joystick.begin(false);
  startedMs = millis();
  lastFrameUs = micros();
}

int axisIndex(const char* name) {
  if (strcmp(name, "throttle") == 0) return kThrottle;
  if (strcmp(name, "clutch") == 0 && CLUTCH_ENABLED) return kClutch;
  if (strcmp(name, "brake") == 0) return kBrake;
  return -1;
}

void startCapture(int8_t kind) {
  if (!brakeHealthy(millis())) {
    reply(PSTR("ERR BRAKE_NOT_READY"));
    return;
  }
  if (kind <= kBrake && !(capturesDone & 8)) {
    reply(PSTR("ERR CAPTURE_REST_FIRST"));
    return;
  }
  for (uint8_t i = 0; i < 3; ++i) captures[i] = pedals::Capture();
  capturing = kind;
  captureStarted = millis();
  neutral();
  reply(PSTR("OK WAIT"));
}

bool parseDeadzone(char** input, uint16_t* result, char end) {
  char* p = *input;
  if (*p < '0' || *p > '9') return false;
  uint16_t value = 0;
  while (*p >= '0' && *p <= '9') {
    value = value * 10 + (*p++ - '0');
    if (value > 100) return false;
  }
  if (*p != end) return false;
  *input = end ? p + 1 : p;
  *result = value;
  return true;
}

// Printf %ld/%lu require long even when the host tests use 64-bit long.
// NOLINTBEGIN(runtime/int)
void handleCommand() {
  lastCommandMs = millis();
  if (!strcmp(command, "CAL CANCEL")) {
    session = false;
    capturing = -1;
    reply(PSTR("OK CANCELLED"));
    return;
  }
  if (capturing >= 0) {
    reply(PSTR("ERR BUSY"));
    return;
  }
  if (!strcmp(command, "INFO")) {
    reply(PSTR("OK INFO protocol=1 firmware=" PEDALS_VERSION
               " calibrated=%u session=%u clutch=%u brake_ok=%u target_hz=%lu"),
          calibrated, session, CLUTCH_ENABLED, brakeHealthy(millis()),
          1000000UL / REPORT_INTERVAL_US);
  } else if (!strcmp(command, "READ")) {
    reply(PSTR("OK READ raw=%ld,%ld,%ld out=%u,%u,%u brake_ok=%u age_ms=%lu"
               " uptime_ms=%lu reports=%lu hall_samples=%lu brake_samples=%lu"),
          static_cast<long>(sensorRaw[0]), static_cast<long>(sensorRaw[1]),
          static_cast<long>(sensorRaw[2]), output[0], output[1], output[2],
          brakeHealthy(millis()),
          static_cast<unsigned long>(millis() - lastBrakeMs),
          static_cast<unsigned long>(millis()),
          static_cast<unsigned long>(reports),
          static_cast<unsigned long>(hallSamples),
          static_cast<unsigned long>(brakeSamples));
  } else if (!strcmp(command, "CAL BEGIN")) {
    if (session) {
      reply(PSTR("ERR ALREADY_CALIBRATING"));
      return;
    }
    candidate = {};
    for (uint8_t i = 0; i < 3; ++i) {
      candidate.axes[i].lower = DEFAULT_DEADZONE;
      candidate.axes[i].upper = DEFAULT_DEADZONE;
    }
    session = true;
    capturesDone = 0;
    neutral();
    reply(PSTR("OK BEGIN"));
  } else if (!strcmp(command, "CAL SHOW")) {
    const Calibration& cal = session ? candidate : active;
    reply(PSTR("OK CAL rest=%ld,%ld,%ld full=%ld,%ld,%ld lower=%u,%u,%u "
               "upper=%u,%u,%u"),
          static_cast<long>(cal.axes[0].rest),
          static_cast<long>(cal.axes[1].rest),
          static_cast<long>(cal.axes[2].rest),
          static_cast<long>(cal.axes[0].full),
          static_cast<long>(cal.axes[1].full),
          static_cast<long>(cal.axes[2].full), cal.axes[0].lower,
          cal.axes[1].lower, cal.axes[2].lower, cal.axes[0].upper,
          cal.axes[1].upper, cal.axes[2].upper);
  } else if (!strcmp(command, "t") || !strcmp(command, "TARE")) {
    if (session || !calibrated) {
      reply(PSTR("ERR CALIBRATION_REQUIRED"));
      return;
    }
    startCapture(4);
  } else if (!strncmp(command, "CAL ", 4)) {
    if (!session) {
      reply(PSTR("ERR BEGIN_REQUIRED"));
      return;
    }
    if (!strcmp(command, "CAL REST")) {
      startCapture(3);
    } else if (!strncmp(command, "CAL FULL ", 9)) {
      int axis = axisIndex(command + 9);
      if (axis < 0)
        reply(PSTR("ERR AXIS"));
      else
        startCapture(axis);
    } else if (!strncmp(command, "CAL DZ ", 7)) {
      char* name = command + 7;
      char* separator = strchr(name, ' ');
      if (!separator) {
        reply(PSTR("ERR DEADZONE_RANGE"));
        return;
      }
      *separator = 0;
      int axis = axisIndex(name);
      char* values = separator + 1;
      uint16_t lower = 0, upper = 0;
      if (axis < 0 || !parseDeadzone(&values, &lower, ' ') ||
          !parseDeadzone(&values, &upper, '\0')) {
        reply(PSTR("ERR DEADZONE_RANGE"));
        return;
      }
      candidate.axes[axis].lower = lower;
      candidate.axes[axis].upper = upper;
      reply(PSTR("OK DEADZONE"));
    } else if (!strcmp(command, "CAL SAVE")) {
      uint8_t required = CLUTCH_ENABLED ? 15 : 13;
      if (capturesDone != required ||
          !pedals::validCalibration(candidate, CLUTCH_ENABLED)) {
        reply(PSTR("ERR INCOMPLETE_CALIBRATION"));
        return;
      }
      if (!brakeHealthy(millis())) {
        reply(PSTR("ERR BRAKE_NOT_READY"));
        return;
      }
      neutral();
      sendReport();  // EEPROM writes happen only in neutral setup mode.
      if (!storage.save(candidate)) {
        reply(PSTR("ERR EEPROM"));
        return;
      }
      active = candidate;
      calibrated = true;
      session = false;
      reply(PSTR("OK SAVED"));
    } else {
      reply(PSTR("ERR COMMAND"));
    }
  } else {
    reply(PSTR("ERR COMMAND"));
  }
}

// NOLINTEND

void serviceSerial() {
  // Bounded work and no blocking writes when a terminal stops reading.
  if (!Serial) {
    responseLength = responsePosition = 0;
    commandLength = 0;
    overflow = false;
    return;
  }
  if (responsePosition < responseLength) {
    int room = Serial.availableForWrite();
    uint16_t remaining = responseLength - responsePosition;
    if (room > 0) {
      size_t count = remaining < room ? remaining : room;
      responsePosition += Serial.write(
          reinterpret_cast<const uint8_t*>(response) + responsePosition, count);
    }
    return;
  }
  for (uint8_t budget = 0; budget < 16 && Serial.available(); ++budget) {
    char c = Serial.read();
    if (c == '\r') continue;
    if (c == '\n') {
      command[commandLength] = 0;
      if (overflow)
        reply(PSTR("ERR LINE_TOO_LONG"));
      else if (commandLength)
        handleCommand();
      commandLength = 0;
      overflow = false;
      return;
    }
    // Preserve the original single-byte 't' command (no newline required).
    if (c == 't' && commandLength == 0 && !overflow) {
      command[0] = 't';
      command[1] = 0;
      handleCommand();
      return;
    }
    if (static_cast<uint8_t>(c) < 32 || static_cast<uint8_t>(c) > 126)
      overflow = true;
    if (!overflow && commandLength < sizeof(command) - 1)
      command[commandLength++] = c;
    else
      overflow = true;
  }
}

void finishCapture() {
  if (capturing < 0 || uint32_t(millis() - captureStarted) < CAPTURE_MS ||
      responsePosition < responseLength)
    return;
  int8_t kind = capturing;
  capturing = -1;
  if (!brakeHealthy(millis())) {
    reply(PSTR("ERR BRAKE_NOT_READY"));
    return;
  }
  for (uint8_t i = 0; i < 3; ++i) {
    if (i == kClutch && !CLUTCH_ENABLED) continue;
    if (kind == 3 || i == kind || (kind == 4 && i == kBrake)) {
      if (!captures[i].stable(i)) {
        reply(PSTR("ERR UNSTABLE_HOLD_STILL"));
        return;
      }
    }
  }
  if (kind == 3) {
    for (uint8_t i = 0; i < 3; ++i) candidate.axes[i].rest = captures[i].mean();
    capturesDone =
        8;  // Recapturing rest invalidates every previous full endpoint.
  } else if (kind == 4) {
    Calibration adjusted = active;
    int32_t delta = captures[kBrake].mean() - adjusted.axes[kBrake].rest;
    adjusted.axes[kBrake].rest += delta;
    adjusted.axes[kBrake].full += delta;
    if (!pedals::validCalibration(adjusted, CLUTCH_ENABLED)) {
      reply(PSTR("ERR TARE_RANGE"));
      return;
    }
    active = adjusted;  // Temporary offset only; never writes EEPROM.
  } else {
    candidate.axes[kind].full = captures[kind].mean();
    if (!pedals::validAxis(candidate.axes[kind], kind)) {
      capturesDone &= ~(1 << kind);
      reply(PSTR("ERR TRAVEL_TOO_SMALL"));
      return;
    }
    capturesDone |= 1 << kind;
  }
  reply(PSTR("OK CAPTURE"));
}

void loop() {
  uint32_t now = millis();
  bool freshBrake = LoadCell.update();
  if (freshBrake) {
    float sample = LoadCell.getData();
    if (sample > 0 && sample < pedals::kBrakeMax) {
      sensorRaw[kBrake] = static_cast<int32_t>(sample);
      lastBrakeMs = now;
      brakeFault = false;
      ++brakeSamples;
      if (capturing >= 0 && uint32_t(now - captureStarted) < CAPTURE_MS)
        captures[kBrake].add(sensorRaw[kBrake]);
    } else {
      brakeFault = true;
    }
  }
  if ((session || capturing >= 0) &&
      uint32_t(now - lastCommandMs) >= CALIBRATION_IDLE_MS) {
    session = false;
    capturing = -1;
  }
  uint32_t tick = micros();
  if (uint32_t(tick - lastFrameUs) >= REPORT_INTERVAL_US) {
    lastFrameUs =
        tick;  // Do not replay a backlog after a slow host or EEPROM save.
    sensorRaw[kThrottle] = readPedal(Throttle, Throttle_I2, use_Dual_Thr);
    sensorRaw[kClutch] =
        CLUTCH_ENABLED ? readPedal(Clutch, Clutch_I2, use_Dual_Cl) : 0;
    ++hallSamples;
    if (capturing >= 0 && uint32_t(now - captureStarted) < CAPTURE_MS) {
      captures[kThrottle].add(sensorRaw[kThrottle]);
      if (CLUTCH_ENABLED) captures[kClutch].add(sensorRaw[kClutch]);
    }
    neutral();
    if (calibrated && !session && capturing < 0 &&
        uint32_t(now - startedMs) >= SENSOR_WARMUP_MS) {
      output[kThrottle] =
          pedals::normalize(sensorRaw[kThrottle], active.axes[kThrottle]);
      if (CLUTCH_ENABLED)
        output[kClutch] =
            pedals::normalize(sensorRaw[kClutch], active.axes[kClutch]);
      if (brakeHealthy(now))
        output[kBrake] =
            pedals::normalize(sensorRaw[kBrake], active.axes[kBrake]);
      if (BRAKE_POT_ENABLED)
        output[kBrake] = static_cast<uint32_t>(output[kBrake]) *
                         (1023 - analogRead(BrakeResistance)) / 1023;
    }
    sendReport();
  }
  finishCapture();
  serviceSerial();
}

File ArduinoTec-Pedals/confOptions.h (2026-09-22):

#ifndef ARDUINOTEC_PEDALS_CONFOPTIONS_H_
#define ARDUINOTEC_PEDALS_CONFOPTIONS_H_

// Default wiring: 5 V / 16 MHz ATmega32u4 + HX711 channel A, gain 128.
#define Throttle A0
#define Clutch A2
#define Throttle_I2 A5
#define Clutch_I2 A8
#define BrakeResistance A3
#define HX711_dout 3
#define HX711_sck 5

#define CLUTCH_ENABLED true
#define use_Dual_Thr false
#define use_Dual_Cl false
// Saved maximum brake pressure replaces the old sensitivity knob by default.
#define BRAKE_POT_ENABLED false

#define REPORT_INTERVAL_US 1000UL
#define BRAKE_TIMEOUT_MS 250UL
#define SENSOR_WARMUP_MS 2000UL
#define CAPTURE_MS 800UL
#define CALIBRATION_IDLE_MS 120000UL
#define DEFAULT_DEADZONE 5  // 0.5%, in parts per thousand, at each endpoint.

// Bump when changing sensor wiring or processing so old EEPROM data is
// rejected.
#define CALIBRATION_PROFILE 1UL
#endif  // ARDUINOTEC_PEDALS_CONFOPTIONS_H_

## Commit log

2023-12-27 pre-commit hooks and fixes
    [CPPLINT.cfg]
2023-12-27 added vscode arduino support
2023-12-27 Updated circuit diagram and readme
    [Circuit.fzz]
2023-12-27 updated schematic
    [Circuit.fzz]
2026-09-22 Fix pedal release and sampling reliability with regression coverage
    [ArduinoTec-Pedals.ino, confOptions.h, pedals_test.cpp]
2026-09-22 Add persistent calibration and guided USB serial setup
2026-09-22 Build release firmware for three boards and document setup and performance
